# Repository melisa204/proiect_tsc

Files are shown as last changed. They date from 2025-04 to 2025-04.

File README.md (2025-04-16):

# TSC-Project

## BOM (Bill Of Materials)

| Component  | Supplier Link | Datasheet |
|---|---|---|
| 112A-TAAR-R03 | [Model](https://store.comet.srl.ro/Catalogue/Product/43497/) | [Datasheet](https://www.snapeda.com/parts/112A-TAAR-R03/Attend/datasheet/) |
| 744043680 | [Model](https://ro.mouser.com/ProductDetail/Wurth-Elektronik/744043680?qs=PGXP4M47uW6VkZq%252BkzjrHA%3D%3D) | [Datasheet](https://www.we-online.com/components/products/datasheet/744043680.pdf) |
| BD5229G-TR | [Model](https://componentsearchengine.com/part-view/BD5229G-TR/ROHM%20Semiconductor) | [Datasheet](https://fscdn.rohm.com/en/products/databook/datasheet/ic/power/voltage_detector/bd52xxg-e.pdf) |
| Capacitor 0402 | [Model](https://ro.mouser.com/c/passive-components/capacitors/ceramic-capacitors/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) | [Datasheet](https://componentsearchengine.com/Datasheets/2/CC0402MRX5R5BB106.pdf) |
| CPH3225A | [Model](https://www.snapeda.com/parts/CPH3225A/Seiko+Instruments/view-part/?ref=snap) | [Datasheet](https://www.snapeda.com/parts/CPH3225A/Seiko%20Instruments/datasheet/) |
| Custom Button | [Model](https://industry.panasonic.com/global/en/products/control/switch/light-touch/number/evqpuj02k) | [Datasheet](https://industry.panasonic.com/global/en/downloads?tab=catalog&small_g_cd=203&part_no=EVQPUJ02K) |
| DS3231SN | [Model](https://www.snapeda.com/parts/DS3231SN%23/Analog+Devices/view-part/?ref=eda) | [Datasheet](https://www.snapeda.com/parts/DS3231SN%23/Analog%20Devices/datasheet/) |
| ESP32 WROVER 0805 Capacitor | [Model](https://componentsearchengine.com/part-view/SD0805S020S1R0/Kyocera%20AVX) | [Datasheet]() |
| ESP32 WROVER BME680 Sensor | [Model](https://www.snapeda.com/parts/BME680/Bosch/view-part/?welcome=home) | [Datasheet](https://www.bosch-sensortec.com/media/boschsensortec/downloads/datasheets/bst-bme680-ds001.pdf) |
| ESP32 WROVER MCP73831 Power Management | [Model](https://www.snapeda.com/parts/BME680/Bosch/view-part/?welcome=home) | [Datasheet](https://www.snapeda.com/parts/MCP73831T-2ACI/OT/Microchip/datasheet/) |
| ESP32C6 Varistor 1812 | [Model](https://ro.mouser.com/ProductDetail/EPCOS-TDK/B72520T0350K062?qs=dEfas%2FXlABIszF52uu7vrg%3D%3D) | [Datasheet](https://ro.mouser.com/ProductDetail/EPCOS-TDK/B72520T0350K062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) |
| ESP32C6 WROOM-1-N8| [Model](https://www.snapeda.com/parts/ESP32-C6-WROOM-1-N8/Espressif+Systems/view-part/?ref=eda) | [Datasheet](https://www.snapeda.com/parts/ESP32-C6-WROOM-1-N8/Espressif%20Systems/datasheet/) |
| FH34SRJ-24S-0.5SH | [Model](https://ro.mouser.com/ProductDetail/Hirose-Connector/FH34SRJ-24S-0.5SH99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) | [Datasheet](https://www.snapeda.com/parts/FH34SRJ-24S-0.5SH(99)/Hirose%20Connector/datasheet/) |
| LED Chip 0603 | [Model](https://www.snapeda.com/parts/KP-1608SURCK/Kingbright/view-part/?ref=search&t=LED%200603) | [Datasheet](https://www.snapeda.com/parts/KP-1608SURCK/Kingbright/datasheet/) |
| MAX17048G+T10 | [Model](https://www.snapeda.com/parts/MAX17048G+T10/Analog+Devices/view-part/?ref=eda) | [Datasheet](https://www.snapeda.com/parts/MAX17048G+T10/Analog%20Devices/datasheet/) |
| MBR0530 Schottky Diode | [Model](https://www.snapeda.com/parts/MBR0530/Onsemi/view-part/?ref=snap) | [Datasheet](https://www.snapeda.com/parts/MBR0530/ON%20Semiconductor/datasheet/) |
| PGB1010603MR | [Model](https://www.snapeda.com/parts/PGB1010603MR/Littelfuse/view-part/?ref=eda) | [Datasheet](https://www.snapeda.com/parts/PGB1010603MR/Littelfuse%20Inc./datasheet/) |
| QWIIC Connector | [Model](https://www.snapeda.com/parts/PRT-14417/SparkFun/view-part/) | [Datasheet](https://www.snapeda.com/parts/PRT-14417/SparkFun%20Electronics/datasheet/) |
| RCL CPOL 3528 | [Model](https://www.snapeda.com/parts/CPH3225A/Seiko+Instruments/view-part/?ref=eda) | [Datasheet](https://s3.amazonaws.com/snapeda/datasheet/TAJB475K025RNJ_AVX.pdf) |
| Resistor 0402 | [Model](https://grabcad.com/library/resistor-0402-1) | [Datasheet](https://www.yageo.com/upload/media/product/products/datasheet/rchip/PYu-RC_Group_51_RoHS_L_12.pdf) |
| SI1308EDL-T1-GE3 MOSFET | [Model](https://www.snapeda.com/parts/SI1308EDL-T1-GE3/Vishay+Siliconix/view-part/?welcome=home&ref=eda) | [Datasheet](https://www.snapeda.com/parts/SI1308EDL-T1-GE3/Vishay%20Siliconix/datasheet/) |
| SJ | [Model](https://grabcad.com/library/solder-jumpers-1) | [Datasheet]() |
| USB4110-GF-A | [Model](https://componentsearchengine.com/part-view/USB4110-GF-A/GCT%20(GLOBAL%20CONNECTOR%20TECHNOLOGY)) | [Datasheet](https://gct.co/files/drawings/usb4110.pdf) |
| USBLC6-2SC6Y | [Model](https://www.snapeda.com/parts/USBLC6-2SC6Y/STMicroelectronics/view-part/?welcome=home&ref=eda) | [Datasheet](https://www.snapeda.com/parts/USBLC6-2SC6Y/STMicroelectronics/datasheet/) |
| W25Q512JVEIQ | [Model](https://www.snapeda.com/parts/W25Q512JVEIQ/Winbond+Electronics/view-part/?ref=eda) | [Datasheet](https://www.winbond.com/resource-files/W25Q512JV%20SPI%20RevB%2006252019%20KMS.pdf) |
| XC6220A331MR-G | [Model](https://componentsearchengine.com/part-view/XC6220A331MR-G/Torex) | [Datasheet](https://product.torexsemi.com/system/files/series/xc6220.pdf) |

## Power Consumption Estimation
Block Diagram

## Hardware Description  

1. Microcontroller – ESP32-C6-WROOM-1-N8
The ESP32-C6 serves as the main processing unit, managing overall system operations, interfacing with
sensors and external modules, and overseeing power management tasks.
Architecture: 32-bit RISC-V
Clock Speed: 160 MHz
Wireless Connectivity: Wi-Fi 6 (2.4 GHz), Bluetooth 5.0

3. Power Management & Battery Battery Type: Li-Po (Lithium Polymer)
Capacity: 3.7V, 1800mAh
Charging Circuit: MCP73831T
Input Voltage: 5V via USB-C
Protection Features: Overcharge and deep discharge protection
Voltage Regulator: LDO regulator ensures a stable 3.3V power supply to all components.

4. Display - E-Paper (E-Ink) Screen
Size: 7.5 inches
Resolution: 800x480 pixels
Communication Interface: SPI

5. SD Card Module
Type: MicroSD (Supports FAT32)
Interface: SPI

6. External NOR Flash
Capacity: 64MB
Interface: SPI

7. Environmental Sensor - BME688
Functions: Measures temperature, humidity, air pressure, and gas levels.
Communication Interface: I2C 

8. Real-Time Clock (RTC) - DS3231SN
Functionality: Maintains time and date even when the system is powered off.
Communication Interface: I2C 

9. USB-C Connector & ESD Protection
Functionality: Provides power input and data transfer capability.
Protection: Integrated ESD protection and Schottky diode for reverse polarity safety. 

10. Buttons & User Input
Tactile Push Buttons

11. Communication Interfaces
GPIO: Used for button controls and general I/O operations.
SPI: Used for SD card, external flash memory, and e-paper display.
I2C: Used for the BME688 environmental sensor and DS3231SN RTC module.
UART: Used for debugging and serial communication.
Wi-Fi & Bluetooth: Provided by ESP32-C6, allowing wireless connectivity.

## Power Consumption Estimation

| Component | Current Draw (mA) | Voltage (V) | Power (mW) |
|---|---|---|---|
| ESP32-C6 (Wi-Fi active)  |200 |3.3 |660
| E-Paper Display (Updating) | 40 | 3.3 | 132 |
| BME688 Sensor (Measuring)| 3.1 | 3.3 | 10.23 |
| RTC Module (Active) | 0.15 | 3.3 | 0.495 |
| SD Card (Active) | 50 | 3.3 | 165 |
| Externar NOR Flash | 25 | 3.3 | 82.5 |
| Total Estimated Power Consumption | ~318.5mA | 3.3 | 1050.72 |

## ESP32-C6 Pin Mapping  

| Component | ESP32-C6 Pin(s) | Interface | Purpose |
|---|---|---|---|
| **E-Paper Display** | IO7 (MOSI), IO6 (SCK), IO10 (CS), IO5 (DC), IO23 (RST), IO3 (BUSY) | SPI | Transfers image data to the display and controls its state. |
| **MicroSD Card** | IO7 (MOSI), IO6 (SCK), IO4 (SS_SD), IO2 (MISO) | SPI | Allows storage and retrieval of e-book files. |
| **Environmental Sensor (BME688)** | IO21 (SDA), IO22 (SCL) | I2C | Reads temperature, humidity, pressure, and air quality data. |
| **RTC Module (DS3231)**  | IO21 (SDA), IO22 (SCL), IO18 (RST), IO1 (32KHz), IO0 (INT_RTC) | I2C | Keeps track of time even when ESP32 is off. |
| **External NOR Flash** | IO11 (CS), IO6 (SCK), IO2 (MISO), IO7 (MOSI) | SPI | Provides additional storage for application data. |
| **Battery Monitoring** | IO21 (SDA), IO22 (SCL) | I2C | Reads battery voltage and charge status. |
| **USB-C Connection** | GPIOs through voltage regulation | USB | Powers and programs the ESP32-C6. |
| **Control Buttons** | IO9 (BOOT), IO15 (CHANGE), EN (RESET) | GPIO | User input for device interactions. |
|

## Additional Design Notes
### Footprint Adjustments
Diode (SMD-Hole): The original footprint had pad holes that were too small, which would have caused soldering issues.
The pad size was updated to 35mil x 190mil to ensure manufacturability and a reliable electrical connection.

U4 – MAX17048G+T10: The VBAT power trace was designed with a width of 0.3mm, based on implementation constraints
However, the footprint had pin widths of only 0.27mm, resulting in asymmetry and inconsistent routing. The pin sizes
were adjusted to match the trace width and maintain design symmetry.

### Routing & Ground Plane
Power traces were routed only on the top layer, which required the use of approximately 110 vias to allow for
signal routing on the bottom layer.

The ground plane (GND) was added after routing was completed, applied to both top and bottom layers to ensure
low-impedance grounding and reduced EMI.

### Component Placement
Test pads (TPs) were placed near the edges of the board and close to major components for easy debugging access.

### Schematic & 3D Model Issues
After completing the routing process, updates to the 3D models led to pin order reversals in certain 2-pin components, 
which disrupted existing connections. The issue was resolved by rotating the affected components 180° and re-aligning their 
pins accordingly.

### Enclosure & 3D Integration
3D components were imported using two methods, depending on how frequently each part appeared in the schematic.

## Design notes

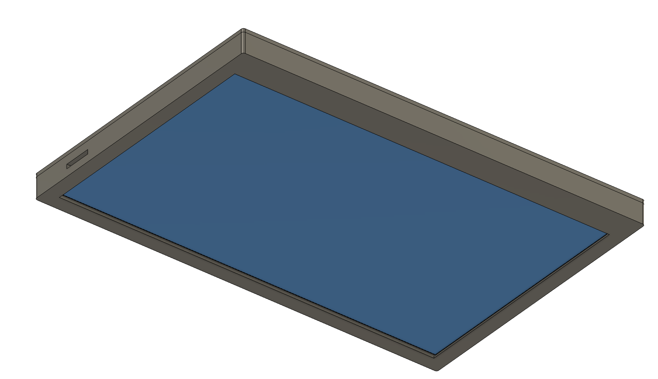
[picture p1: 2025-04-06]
Images/Screenshot 2025-04-06 at 20.57.26.png

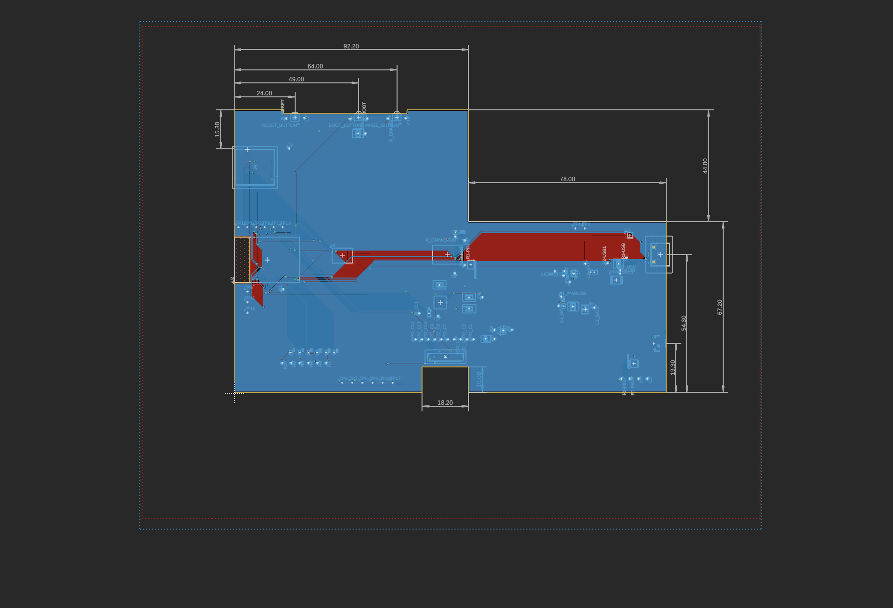
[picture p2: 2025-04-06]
Images/Screenshot 2025-04-06 at 20.54.19.png

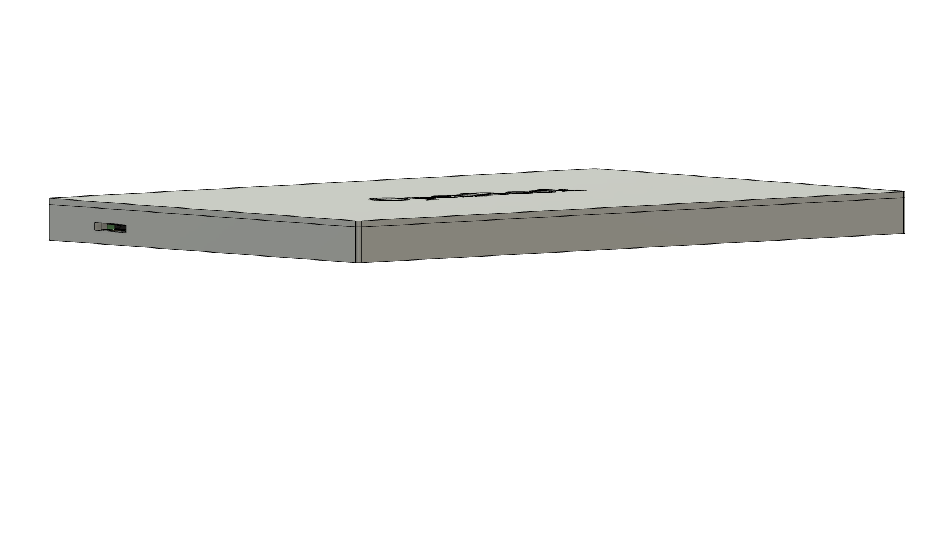
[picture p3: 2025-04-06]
Images/Screenshot 2025-04-06 at 20.57.17.png

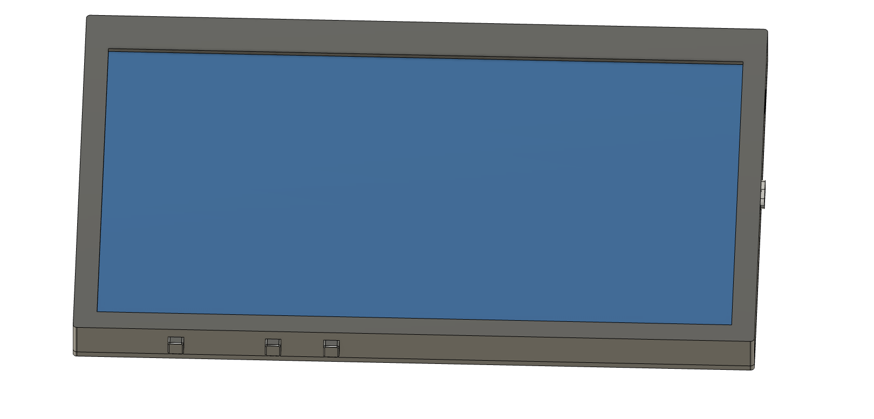
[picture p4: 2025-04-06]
Images/Screenshot 2025-04-06 at 20.56.48.png

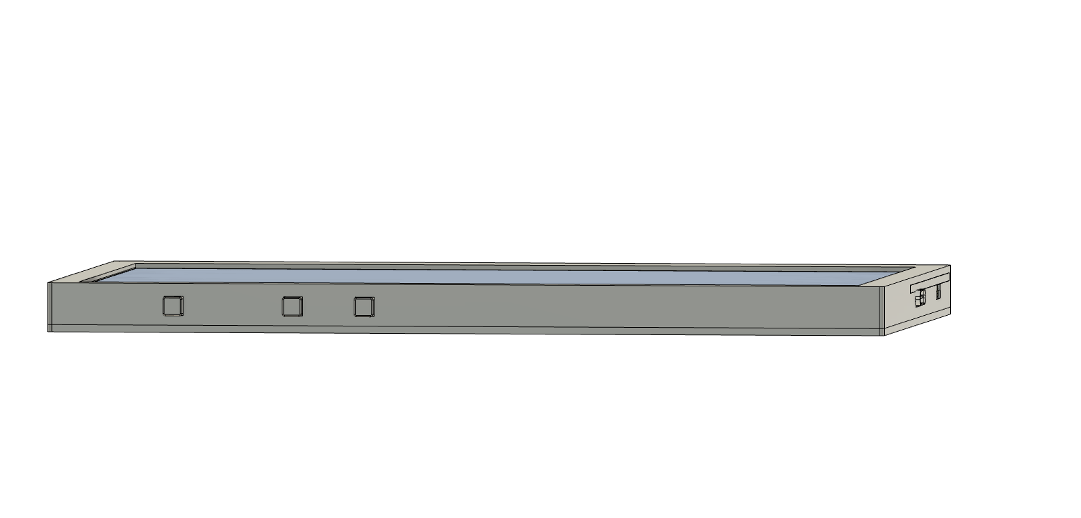
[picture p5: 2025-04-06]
Images/Screenshot 2025-04-06 at 20.56.39.png

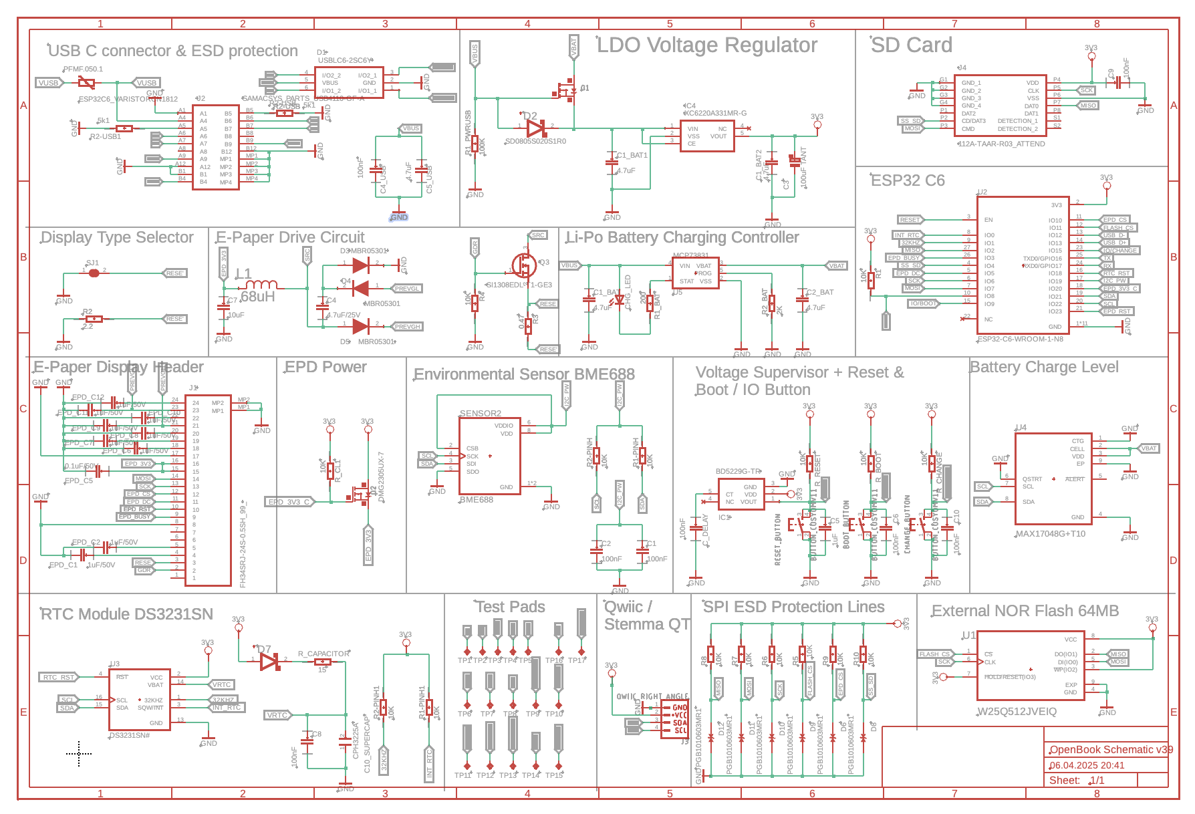
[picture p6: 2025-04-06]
Images/Screenshot 2025-04-06 at 20.53.59.png

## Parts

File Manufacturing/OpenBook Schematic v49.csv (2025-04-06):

Qty | Value | Device | Package | Parts | Description | ARROW_PART_NUMBER | ARROW_PRICE-STOCK | AVAILABILITY | CHECK_PRICES | COPYRIGHT | DESCRIPTION | HEIGHT | MANUFACTURER_NAME | MANUFACTURER_PART_NUMBER | MF | MFR_NAME | MINE | MOUSER_PART_NUMBER | MOUSER_PRICE-STOCK | MOUSER_TESTING_PART_NUMBER | MOUSER_TESTING_PRICE-STOCK | MP | PACKAGE | POPULARITY | PRICE | PROD_ID | PURCHASE-URL | R2-USB | SNAPEDA_LINK | SPICEPREFIX | TP_SIGNAL_NAME | VALUE
1 |  | ADAFRUIT_LEDCHIP-LED0603 | ADAFRUIT_CHIP-LED0603 | CHG_LED | LED
1 |  | SJ | SJ | SJ1 | SMD solder JUMPER |  |  |  |  |  |  |  |  |  |  |  |  |  |  |  |  |  |  | 3
1 | 0.1uF/50V | EAGLE-LTSPICE_C | EAGLE-LTSPICE_C0402 | EPD_C5 | CAPACITOR, European symbol
1 | 0.47 | ESP32_WROVER_EAGLE-LTSPICE_R | ESP32_WROVER_EAGLE-LTSPICE_R0402 | R3 | RESISTOR, European symbol
1 | 100K | ESP32_WROVER_EAGLE-LTSPICE_R | ESP32_WROVER_EAGLE-LTSPICE_R0402 | R1_PWRUSB | RESISTOR, European symbol
8 | 100nF | EAGLE-LTSPICE_C | EAGLE-LTSPICE_C0402 | C1, C2, C4_USB, C6, C8, C9, C10, C_DELAY | CAPACITOR, European symbol
1 | 100uF TANT | RCL_CPOL-EUCT3528 | RCL_CT3528 | C3 | POLARIZED CAPACITOR, European symbol |  |  |  |  |  |  |  |  |  |  |  |  |  |  |  |  |  |  | 0 |  |  |  |  |  | C
16 | 10K | ESP32_WROVER_EAGLE-LTSPICE_R | ESP32_WROVER_EAGLE-LTSPICE_R0402 | R1, R1-PINH, R1-PINH1, R2-PINH, R2-PINH1, R4, R5, R6, R7, R8, R9, R10, R_BOOT, R_CHANGE, R_CL1, R_RESET | RESISTOR, European symbol
1 | 10uF | EAGLE-LTSPICE_C | EAGLE-LTSPICE_C0402 | C7 | CAPACITOR, European symbol
1 | 112A-TAAR-R03_ATTEND | 112A-TAAR-R03_ATTEND | 112ATAARR03ATTEND | J4 | Micro SD Card Socket, Push-Push Type, Top Mount, SMT, H=1.83mm, 10u |  |  |  |  |  | Micro SD Card Socket | Push-Push Type | Top Mount | SMT | H=1.83mm | 10u | 1.9mm | ATTEND | 112A-TAAR-R03 ATTEND
1 | 15 | ESP32_WROVER_EAGLE-LTSPICE_R | ESP32_WROVER_EAGLE-LTSPICE_R0402 | R_CAPACITOR | RESISTOR, European symbol
1 | 1uF | EAGLE-LTSPICE_C | EAGLE-LTSPICE_C0402 | C5 | CAPACITOR, European symbol
9 | 1uF/50V | EAGLE-LTSPICE_C | EAGLE-LTSPICE_C0402 | EPD_C1, EPD_C2, EPD_C6, EPD_C7, EPD_C8, EPD_C9, EPD_C10, EPD_C11, EPD_C12 | CAPACITOR, European symbol
1 | 2.2 | ESP32_WROVER_EAGLE-LTSPICE_R | ESP32_WROVER_EAGLE-LTSPICE_R0402 | R2 | RESISTOR, European symbol
1 | 200 | ESP32_WROVER_EAGLE-LTSPICE_R | ESP32_WROVER_EAGLE-LTSPICE_R0402 | R1_BAT | RESISTOR, European symbol
1 | 20V/4.2A/52mΩ/1.4W | ESP32_WROVER_SPARKFUN-DISCRETESEMI_MOSFET_PCH | ESP32_WROVER_SPARKFUN-DISCRETESEMI_SOT23-3 | Q1 | P-channel MOSFETs
1 | 20V/4.2A/52mΩ/1.4W | ESP32_WROVER_SPARKFUN-DISCRETESEMI_MOSFET_PCH | ESP32_WROVER_SPARKFUN-DISCRETESEMI_SOT23-3 | Q2 | P-channel MOSFETs |  |  |  |  |  |  |  |  |  |  |  | DMG2305UX-7
1 | 2K | ESP32_WROVER_EAGLE-LTSPICE_R | ESP32_WROVER_EAGLE-LTSPICE_R0402 | R2_BAT | RESISTOR, European symbol
5 | 4.7uF | EAGLE-LTSPICE_C | EAGLE-LTSPICE_C0402 | C1_BAT, C1_BAT1, C1_BAT2, C2_BAT, C5_USB | CAPACITOR, European symbol
1 | 4.7uF/25V | EAGLE-LTSPICE_C | EAGLE-LTSPICE_C0402 | C4 | CAPACITOR, European symbol
1 | 5k1 | ESP32_WROVER_EAGLE-LTSPICE_R | ESP32_WROVER_EAGLE-LTSPICE_R0402 | R2-USB1 | RESISTOR, European symbol
1 | 5k1 | ESP32_WROVER_EAGLE-LTSPICE_R | ESP32_WROVER_EAGLE-LTSPICE_R0402 | R2-USB | RESISTOR, European symbol |  |  |  |  |  |  |  |  |  |  |  |  |  |  |  |  |  |  |  |  |  |  | 5k1
1 | 68uH | 744043680IND_4828-WE-TPC_WRE | IND_4828-WE-TPC_WRE | L1 |  |  |  |  |  | Copyright (C) 2024 Ultra Librarian. All rights reserved. |  |  |  | 744043680 |  | Wurth Electronics
1 | BD5229G-TR | BD5229G-TR | SOT95P280X125-5N | IC1 | Voltage Detector with Adjustable Delay Time: CMOS processes are utilized to develop high precision, low current consumption CMOS reset ICs that allow arbitrary setting of the delay time. The extensive lineup includes both Nch Open Drain and CMOS output types in a wide range of detection voltages (from 2.3V to 6.0V, in 0.1V steps), enabling selection of the ideal solution based on customer requirements. In addition, the entire series is of course both lead-free and RoHS-compliant. |  |  |  |  |  | Voltage Detector with Adjustable Delay Time: CMOS processes are utilized to develop high precision | low current consumption CMOS reset ICs that allow arbitrary setting of the delay time. The extensive lineup includes both Nch Open Drain and CMOS output types in a wide range of detection voltages (from 2.3V to 6.0V | in 0.1V steps) | enabling selection of the ideal solution based on customer requirements. In addition | the entire series is of course both lead-free and RoHS-compliant. | 1.25mm | ROHM Semiconductor | BD5229G-TR |  |  |  | 755-BD5229G-TR | https://www.mouser.co.uk/ProductDetail/ROHM-Semiconductor/BD5229G-TR?qs=4kLU8WoGk0vvnhrrYwdszw%3D%3D
1 | BME688 | ESP32_WROVER_BME680_BME680 | ESP32_WROVER_BME680_PSON80P300X300X100-8N | SENSOR2 | Integrated Environmental Unit |  |  | Unavailable |  |  | Integrated Environmental Unit |  |  |  | Bosch Sensortec |  |  |  |  |  |  | BME680 | LGA-8 Bosch Tools |  | None
3 | BUTTON_CUSYOMV11 | BUTTON_CUSYOMV11 | MYBUTTON | BOOT_BUTTON, CHANGE_BUTTON, RESET_BUTTON
1 | CPH3225A | CPH3225A | CAPCP3225X100N | C10_SUPERCAP | Cap 0.011F 3.3V 1210 Flat Check availability |  |  | Not in stock | https://www.snapeda.com/parts/CPH3225A/Seiko+Instruments/view-part/?ref=eda |  | 11 mF (EDLC) Supercapacitor 3.3 V 1210 (3225 Metric) - - |  |  |  | Seiko Instruments |  |  |  |  |  |  | CPH3225A | 1210 Seiko |  | None |  | https://www.snapeda.com/api/url_track_click_mouser/?unipart_id=562593&manufacturer=Seiko Instruments&part_name=CPH3225A&search_term=None |  | https://www.snapeda.com/parts/CPH3225A/Seiko+Instruments/view-part/?ref=snap
1 | DS3231SN# | DS3231SN# | SOIC127P1032X265-16N | U3 | Real Time Clock Serial 16-Pin SOIC W T/R Check availability |  |  | In Stock | https://www.snapeda.com/parts/DS3231SN%23/Analog+Devices/view-part/?ref=eda |  | Extremely Accurate I²C-Integrated RTC/TCXO/Crystal |  |  |  | Analog Devices |  |  |  |  |  |  | DS3231SN# | SOIC-16 Maxim |  | None |  | https://www.snapeda.com/api/url_track_click_mouser/?unipart_id=99048&manufacturer=Analog Devices&part_name=DS3231SN#&search_term=None |  | https://www.snapeda.com/parts/DS3231SN%23/Analog+Devices/view-part/?ref=snap
1 | ESP32-C6-WROOM-1-N8 | ESP32-C6-WROOM-1-N8 | XCVR_ESP32-C6-WROOM-1-N8 | U2 | Check availability |  |  | In Stock | https://www.snapeda.com/parts/ESP32-C6-WROOM-1-N8/Espressif+Systems/view-part/?ref=eda |  | Multiprotocol Modules ESP32-C6 module | Wi-Fi 6 in 2.4 GHz band | Bluetooth 5 | Zigbee 3.0 and Thread. ESP34-WROOM Compatible - ENGINEERING SAMPLE |  |  |  | Espressif Systems |  |  |  |  |  |  | ESP32-C6-WROOM-1-N8 | None |  | None |  |  |  | https://www.snapeda.com/parts/ESP32-C6-WROOM-1-N8/Espressif+Systems/view-part/?ref=snap
1 | ESP32C6_VARISTORCN1812 | ESP32C6_VARISTORCN1812 | ESP32C6_VARISTOR_CT/CN1812 | PFMF.050.1 | VARISTOR |  |  |  |  |  |  |  |  |  |  |  |  |  |  |  |  |  |  | 0
1 | FH34SRJ-24S-0.5SH_99_ | FH34SRJ-24S-0.5SH_99_ | FH34SRJ24S05SH99 | J1 | (0.50mm) Surface Mount, Right Angle |  |  |  |  |  | 24 Position FFC | FPC Connector Contacts | (0.50mm) Surface Mount | Right Angle | 1.1mm | Hirose | FH34SRJ-24S-0.5SH(99) |  |  |  | 798-FH34SRJ24S05SH99 | https://www.mouser.co.uk/ProductDetail/Hirose-Connector/FH34SRJ-24S-0.5SH99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
1 | MAX17048G+T10 | MAX17048G+T10 | SON50P200X200X80-9N | U4 | Check availability |  |  | In Stock | https://www.snapeda.com/parts/MAX17048G+T10/Analog+Devices/view-part/?ref=eda |  | 3µA 1-Cell/2-Cell Fuel Gauge with ModelGauge |  |  |  | Analog Devices |  |  |  |  |  |  | MAX17048G+T10 | TDFN-8 Maxim |  | None |  | https://www.snapeda.com/api/url_track_click_mouser/?unipart_id=329239&manufacturer=Analog Devices&part_name=MAX17048G+T10&search_term=None |  | https://www.snapeda.com/parts/MAX17048G+T10/Analog+Devices/view-part/?ref=snap
3 | MBR05301 | MBR05301 | SOD3716X135N | D3, D4, D5 | ON SEMICONDUCTOR - MBR0530 - DIODE, SCHOTTKY, 0.5A, 30V, SOD-123
1 | MCP73831 | ESP32_WROVER_SPARKFUN-IC-POWER_MCP73831 | ESP32_WROVER_SPARKFUN-IC-POWER_SOT23-5 | U5 | MCP73831T Li-Ion, Li-Pol Controller |  |  |  |  |  |  |  |  |  |  |  |  |  |  |  |  |  |  |  |  | IC-09995
6 | PGB1010603MR1 | PGB1010603MR1 | DIOC1608X36N | D6, D8, D9, D10, D11, D12 | Check availability
1 | QWIIC_RIGHT_ANGLE | QWIIC_CONNECTORJS-1MM | JST04_1MM_RA | J3 | SparkFun I2C Standard Qwiic Connector |  |  |  |  |  |  |  |  |  |  |  |  |  |  |  |  |  |  |  |  | CONN-13694 |  |  |  |  |  | QWIIC_RIGHT_ANGLE
1 | SAMACSYS_PARTS_USB4110-GF-A | SAMACSYS_PARTS_USB4110-GF-A | SAMACSYS_PARTS_USB4110GFA | J2 | CONN USB 2.0 TYPE-C R/A SMT |  |  |  |  |  | CONN USB 2.0 TYPE-C R/A SMT | 3.26mm | GCT (GLOBAL CONNECTOR TECHNOLOGY) | USB4110-GF-A |  |  |  | 640-USB4110-GF-A | https://www.mouser.co.uk/ProductDetail/GCT/USB4110-GF-A?qs=KUoIvG%2F9IlYiZvIXQjyJeA%3D%3D
1 | SD0805S020S1R0 | ESP32_WROVER_AVX---SD0805S020S1R0_AVX_SD0805S020S1R0_0_0 | ESP32_WROVER_AVX---SD0805S020S1R0_AVX_SD0805S020S1R0_0 | D7 | Schottky Barrier Rectifier Diode
1 | SD0805S020S1R0 | ESP32_WROVER_AVX---SD0805S020S1R0_AVX_SD0805S020S1R0_0_0 | ESP32_WROVER_AVX---SD0805S020S1R0_AVX_SD0805S020S1R0_0 | D2 | Schottky Barrier Rectifier Diode |  |  |  |  |  |  |  |  |  |  |  | SD0805S020S1R0
1 | SI1308EDL-T1-GE3 | SI1308EDL-T1-GE3 | SOT65P210X110-3N | Q3 | MOSFET N-Ch 30V 1.5A TrenchFET SC70 Vishay Si1308EDL-T1-GE3 N-channel MOSFET Transistor, 1.5 A, 30 V, 3-Pin SC-70 |  |  | In Stock | https://www.snapeda.com/parts/SI1308EDL-T1-GE3/Vishay+Siliconix/view-part/?ref=eda |  | Si1308EDL-T1-GE3 N-channel MOSFET Transistor | 1.5 A | 30 V | 3-Pin SC-70 | Siliconix / Vishay SI1308EDL-T1-GE3 |  |  |  | Vishay Siliconix |  |  |  |  |  |  | SI1308EDL-T1-GE3 | SOT-323 Vishay Semiconductor |  | None |  | https://www.snapeda.com/api/url_track_click_mouser/?unipart_id=274603&manufacturer=Vishay Siliconix&part_name=SI1308EDL-T1-GE3&search_term=None |  | https://www.snapeda.com/parts/SI1308EDL-T1-GE3/Vishay+Siliconix/view-part/?ref=snap
17 | TPTP20R | TPTP20R | TP20R | TP1, TP2, TP3, TP4, TP5, TP6, TP7, TP8, TP9, TP10, TP11, TP12, TP13, TP14, TP15, TP16, TP17 | Test pad |  |  |  |  |  |  |  |  |  |  |  |  |  |  |  |  |  |  | 2
1 | USBLC6-2SC6Y | USBLC6-2SC6Y | SOT95P280X145-6N | D1 | Low Cap. ESD Protection Auto SOT-23-6 STMicroelectronics USBLC6-2SC6Y, Dual Uni-Directional TVS Diode Array, 6-Pin SOT-23 |  |  | In Stock | https://www.snapeda.com/parts/USBLC6-2SC6Y/STMicroelectronics/view-part/?ref=eda |  | 17V Clamp 5A (8/20µs) Ipp Tvs Diode Surface Mount SOT-23-6 |  |  |  | STMicroelectronics |  |  |  |  |  |  | USBLC6-2SC6Y | SOT-23-6 STMicroelectronics |  | None |  |  |  | https://www.snapeda.com/parts/USBLC6-2SC6Y/STMicroelectronics/view-part/?ref=snap
1 | W25Q512JVEIQ | W25Q512JVEIQ | SON127P600X800X80-9N | U1 | Check availability |  |  | In Stock | https://www.snapeda.com/parts/W25Q512JVEIQ/Winbond+Electronics/view-part/?ref=eda |  | FLASH - NOR Memory IC 512Mb (64M x 8) SPI - Quad I/O 133 MHz 8-WSON (8x6) |  |  |  | Winbond Electronics |  |  |  |  |  |  | W25Q512JVEIQ | Package |  | None |  |  |  | https://www.snapeda.com/parts/W25Q512JVEIQ/Winbond+Electronics/view-part/?ref=snap
1 | XC6220A331MR-G | XC6220A331MR-G | SOT95P280X120-5N | IC4 | LDO Voltage Regulators |  |  |  |  |  | LDO Voltage Regulators | 1.2mm | Torex | XC6220A331MR-G |  |  |  | 865-XC6220A331MR-G | https://www.mouser.co.uk/ProductDetail/Torex-Semiconductor/XC6220A331MR-G?qs=AsjdqWjXhJ8ZSWznL1J0gg%3D%3D

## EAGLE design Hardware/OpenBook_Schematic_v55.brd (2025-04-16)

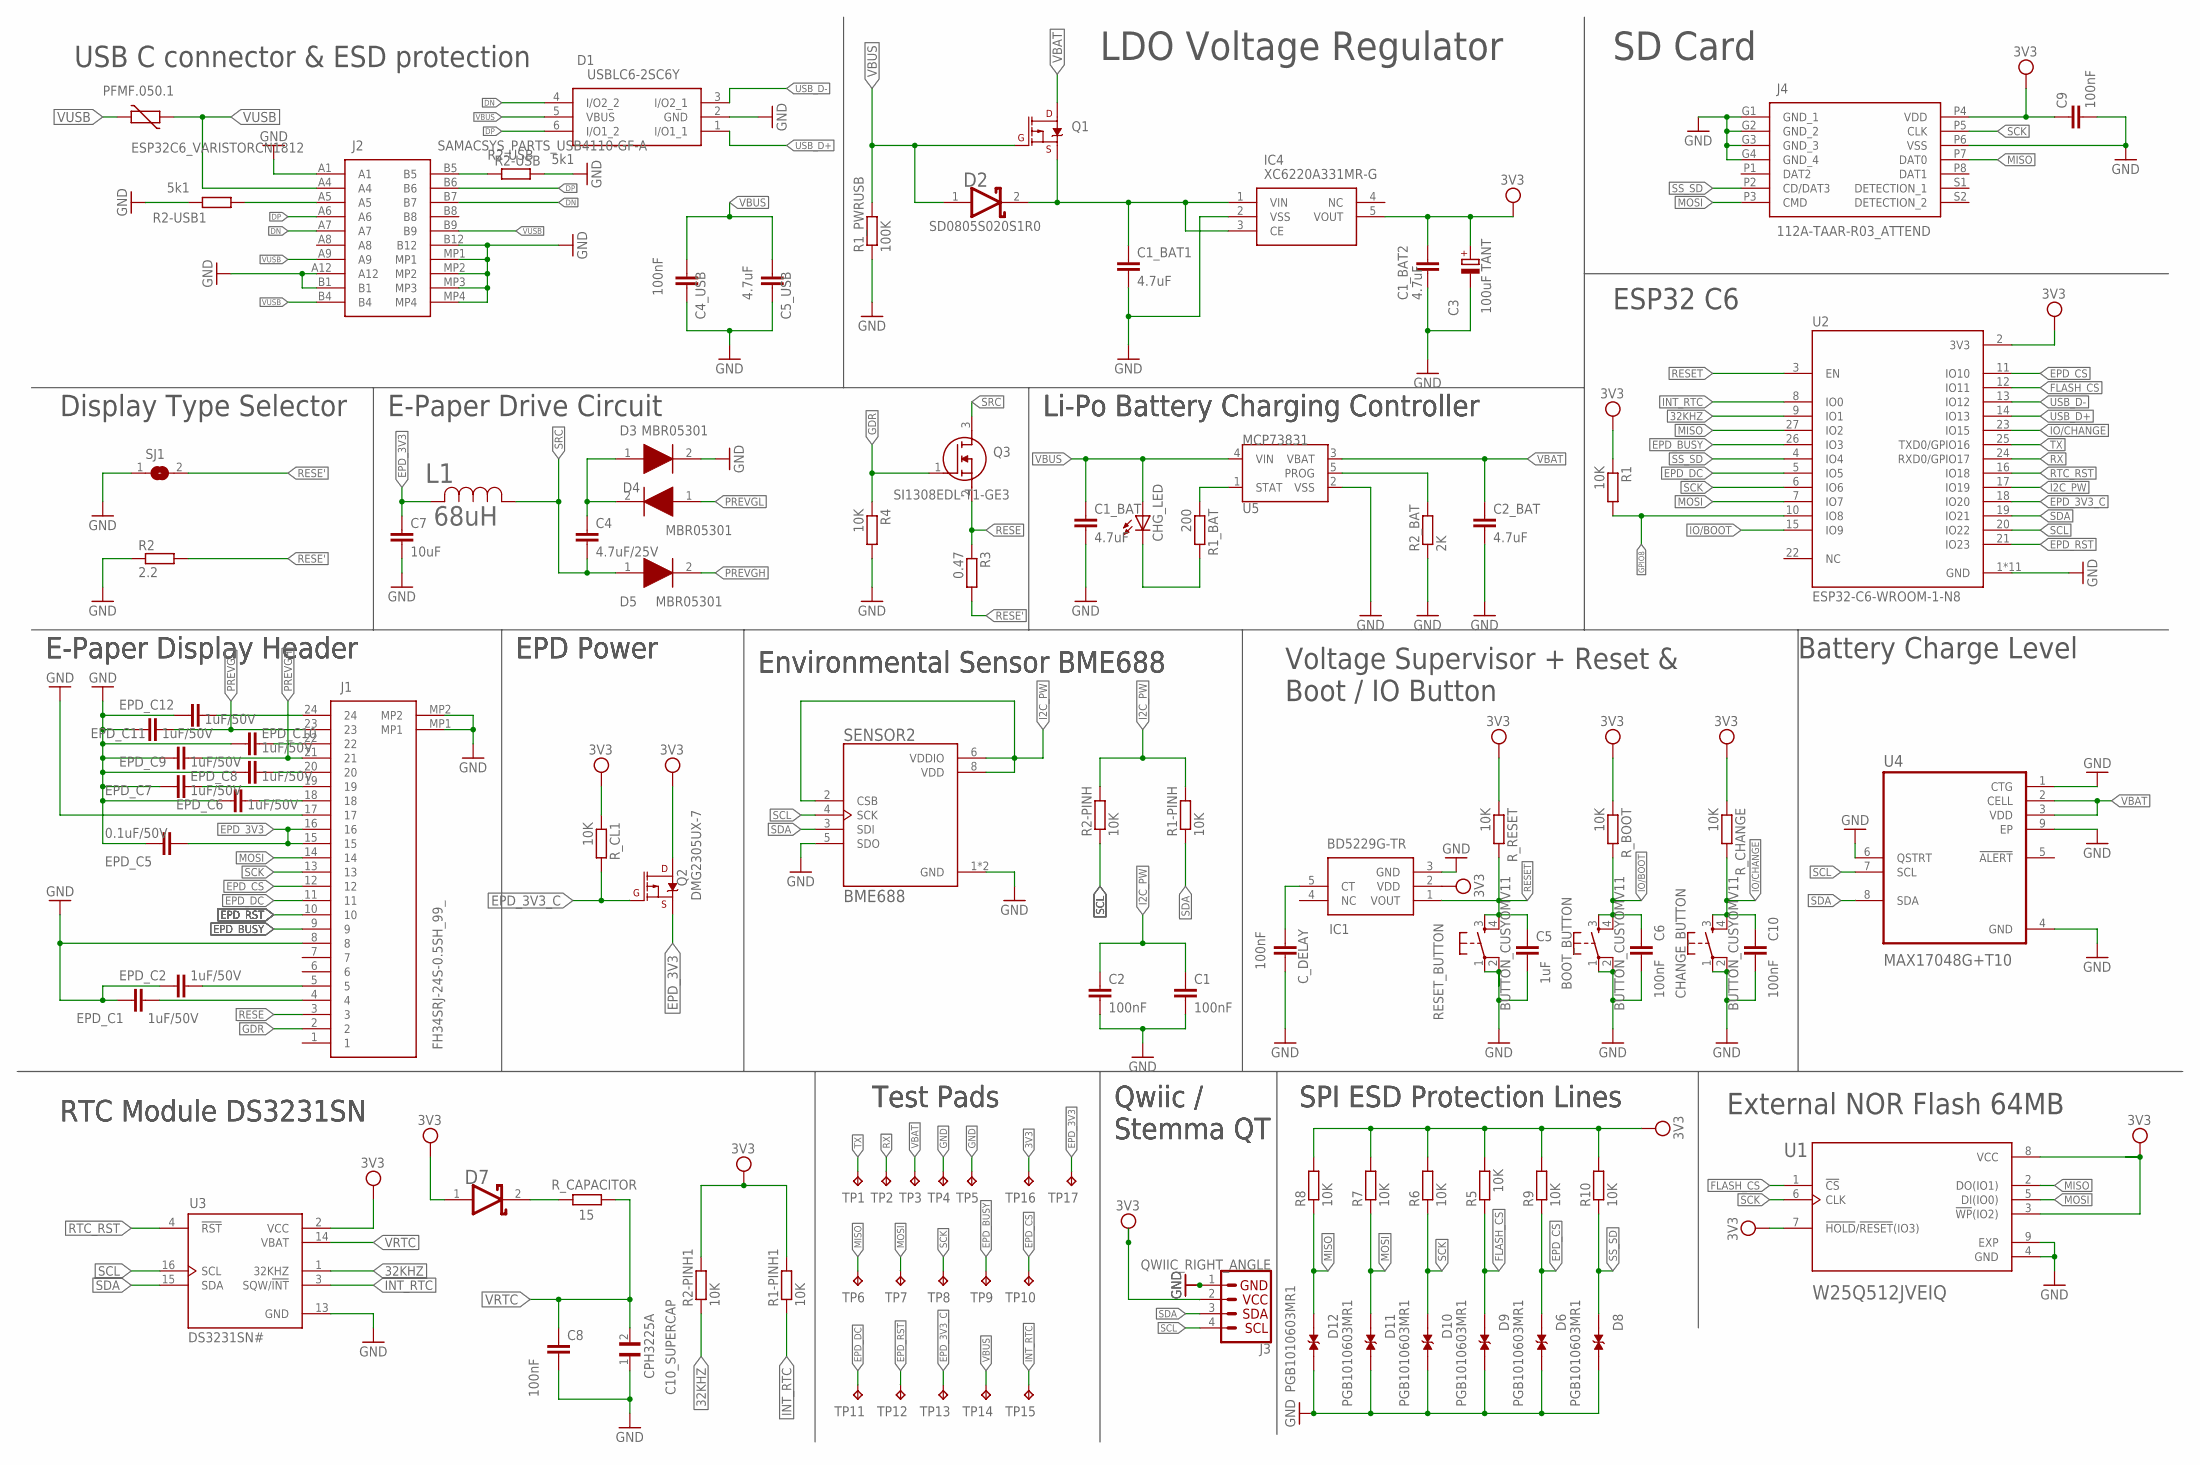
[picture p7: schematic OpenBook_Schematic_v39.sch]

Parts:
BOOT_BUTTON: BUTTON_CUSYOMV11; MYBUTTON
C1, C2, C4_USB, C6, C8, C9, C10: 100nF; EAGLE-LTSPICE_C0402
C1_BAT, C1_BAT1, C1_BAT2, C2_BAT, C5_USB: 4.7uF; EAGLE-LTSPICE_C0402
C3: 100uF TANT; RCL_CT3528
C4: 4.7uF/25V; EAGLE-LTSPICE_C0402
C5: 1uF; EAGLE-LTSPICE_C0402
C7: 10uF; EAGLE-LTSPICE_C0402
C10_SUPERCAP: CPH3225A; CAPCP3225X100N
CHANGE_BUTTON: BUTTON_CUSYOMV11; MYBUTTON
CHG_LED: ADAFRUIT_LEDCHIP-LED0603; ADAFRUIT_CHIP-LED0603
C_DELAY: 100nF; EAGLE-LTSPICE_C0402
D1: USBLC6-2SC6Y; SOT95P280X145-6N
D2, D7: SD0805S020S1R0; ESP32_WROVER_AVX---SD0805S020S1R0_AVX_SD0805S020S1R0_0
D3, D4, D5: MBR05301; SOD3716X135N
D6, D8, D9, D10, D11, D12: PGB1010603MR1; DIOC1608X36N
EPD_C1, EPD_C2, EPD_C6, EPD_C7, EPD_C8, EPD_C9, EPD_C10, EPD_C11, EPD_C12: 1uF/50V; EAGLE-LTSPICE_C0402
EPD_C5: 0.1uF/50V; EAGLE-LTSPICE_C0402
IC1: BD5229G-TR; SOT95P280X125-5N
IC4: XC6220A331MR-G; SOT95P280X120-5N
J1: FH34SRJ-24S-0.5SH_99_; FH34SRJ24S05SH99
J2: SAMACSYS_PARTS_USB4110-GF-A; SAMACSYS_PARTS_USB4110GFA
J3: QWIIC_RIGHT_ANGLE; JST04_1MM_RA
J4: 112A-TAAR-R03_ATTEND; 112ATAARR03ATTEND
L1: 68uH; IND_4828-WE-TPC_WRE
PFMF.050.1: ESP32C6_VARISTORCN1812; ESP32C6_VARISTOR_CT/CN1812
Q1, Q2: 20V/4.2A/52mΩ/1.4W; ESP32_WROVER_SPARKFUN-DISCRETESEMI_SOT23-3
Q3: SI1308EDL-T1-GE3; SOT65P210X110-3N
R1, R1-PINH, R1-PINH1, R2-PINH, R2-PINH1, R4, R5, R6, R7, R8, R9, R10: 10K; ESP32_WROVER_EAGLE-LTSPICE_R0402
R1_BAT: 200; ESP32_WROVER_EAGLE-LTSPICE_R0402
R1_PWRUSB: 100K; ESP32_WROVER_EAGLE-LTSPICE_R0402
R2: 2.2; ESP32_WROVER_EAGLE-LTSPICE_R0402
R2-USB, R2-USB1: 5k1; ESP32_WROVER_EAGLE-LTSPICE_R0402
R2_BAT: 2K; ESP32_WROVER_EAGLE-LTSPICE_R0402
R3: 0.47; ESP32_WROVER_EAGLE-LTSPICE_R0402
RESET_BUTTON: BUTTON_CUSYOMV11; MYBUTTON
R_BOOT: 10K; ESP32_WROVER_EAGLE-LTSPICE_R0402
R_CAPACITOR: 15; ESP32_WROVER_EAGLE-LTSPICE_R0402
R_CHANGE: 10K; ESP32_WROVER_EAGLE-LTSPICE_R0402
R_CL1: 10K; ESP32_WROVER_EAGLE-LTSPICE_R0402
R_RESET: 10K; ESP32_WROVER_EAGLE-LTSPICE_R0402
SENSOR2: BME688; ESP32_WROVER_BME680_PSON80P300X300X100-8N
SJ1: SJ
TP1, TP2, TP3, TP4, TP5, TP6, TP7, TP8, TP9, TP10, TP11, TP12, TP13, TP14, TP15, TP16, TP17: TPTP20R; TP20R
U1: W25Q512JVEIQ; SON127P600X800X80-9N
U2: ESP32-C6-WROOM-1-N8; XCVR_ESP32-C6-WROOM-1-N8
U3: DS3231SN#; SOIC127P1032X265-16N
U4: MAX17048G+T10; SON50P200X200X80-9N
U5: MCP73831; ESP32_WROVER_SPARKFUN-IC-POWER_SOT23-5

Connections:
3V3: C1_BAT2.1, C3.+, C9.1, D7.1 (ANODE), IC1.2 (VDD), IC4.5 (VOUT), J3.2, J4.P4 (VDD), Q2.1 (D), R1.1, R1-PINH1.2, R2-PINH1.2, R5.2, R6.2, R7.2, R8.2, R9.2, R10.2, R_BOOT.1, R_CHANGE.1, R_CL1.1, R_RESET.1, TP16.TP, U1.3 (!WP!(IO2)), U1.7 (!HOLD!/!RESET!(IO3)), U1.8 (VCC), U2.2 (3V3), U3.2 (VCC)
32KHZ: R2-PINH1.1, U2.9 (IO1), U3.1 (32KHZ)
DN: D1.4 (I/O2_2), J2.A7, J2.B7
DP: D1.6 (I/O1_2), J2.A6, J2.B6
EPD_3V3: C7.1, EPD_C5.1, J1.15, J1.16, L1.2, Q2.3 (S), TP17.TP
EPD_3V3_C: Q2.2 (G), R_CL1.2, TP13.TP, U2.18 (IO20)
EPD_BUSY: J1.9, TP9.TP, U2.26 (IO3)
EPD_CS: D6.1, J1.12, R9.1, TP10.TP, U2.11 (IO10)
EPD_DC: J1.11, TP11.TP, U2.5 (IO5)
EPD_RST: J1.10, TP12.TP, U2.21 (IO23)
FLASH_CS: D9.1, R5.1, U1.1 (!CS), U2.12 (IO11)
GDR: J1.2, Q3.1 (G), R4.1
GND: BOOT_BUTTON.1, BOOT_BUTTON.2, C1.2, C1_BAT.2, C1_BAT1.2, C1_BAT2.2, C2.2, C2_BAT.2, C3.-, C4_USB.2, C5.2, C5_USB.2, C6.2, C7.2, C8.2, C9.2, C10.2, C10_SUPERCAP.1, CHANGE_BUTTON.1, CHANGE_BUTTON.2, C_DELAY.2, D1.2 (GND), D3.2 (K), D6.2, D8.2, D9.2, D10.2, D11.2, D12.2, EPD_C1.2, EPD_C2.2, EPD_C5.2, EPD_C6.2, EPD_C7.2, EPD_C8.2, EPD_C9.2, EPD_C10.2, EPD_C11.2, EPD_C12.2, IC1.3 (GND), IC4.2 (VSS), J1.8, J1.17, J1.MP1, J1.MP2, J2.A1, J2.A12, J2.B1, J2.B12, J2.MP1, J2.MP2, J2.MP3, J2.MP4, J3.1, J4.G1 (GND_1), J4.G2 (GND_2), J4.G3 (GND_3), J4.G4 (GND_4), J4.P6 (VSS), R1_PWRUSB.1, R2.1, R2-USB.2, R2-USB1.1, R2_BAT.1, R4.2, RESET_BUTTON.1, RESET_BUTTON.2, SENSOR2.1 (GND), SENSOR2.5 (SDO), SENSOR2.7 (GND), SJ1.1, TP4.TP, TP5.TP, U1.4 (GND), U1.9 (EXP), U2.1 (GND), U2.28 (GND), U2.29_1 (GND), U2.29_2 (GND), U2.29_3 (GND), U2.29_4 (GND), U2.29_5 (GND), U2.29_6 (GND), U2.29_7 (GND), U2.29_8 (GND), U2.29_9 (GND), U3.13 (GND), U4.1 (CTG), U4.4 (GND), U4.6 (QSTRT), U4.9 (EP), U5.2 (VSS)
GPIO8: R1.2, U2.10 (IO8)
I2C_PW: C1.1, C2.1, R1-PINH.2, R2-PINH.2, SENSOR2.2 (CSB), SENSOR2.6 (VDDIO), SENSOR2.8 (VDD), U2.17 (IO19)
INT_RTC: R1-PINH1.1, TP15.TP, U2.8 (IO0), U3.3 (SQW/!INT)
IO/BOOT: BOOT_BUTTON.3, BOOT_BUTTON.4, C6.1, R_BOOT.2, U2.15 (IO9)
IO/CHANGE: C10.1, CHANGE_BUTTON.3, CHANGE_BUTTON.4, R_CHANGE.2, U2.23 (IO15)
MISO: D12.1, J4.P7 (DAT0), R8.1, TP6.TP, U1.2 (DO(IO1)), U2.27 (IO2)
MOSI: D11.1, J1.14, J4.P3 (CMD), R7.1, TP7.TP, U1.5 (DI(IO0)), U2.7 (IO7)
unnamed: C_DELAY.1, IC1.5 (CT)
unnamed: EPD_C6.1, J1.18
unnamed: J2.A5, R2-USB1.2
unnamed: EPD_C1.1, J1.4
unnamed: EPD_C2.1, J1.5
unnamed: EPD_C7.1, J1.19
unnamed: EPD_C8.1, J1.20
unnamed: R1_BAT.1, U5.1 (STAT)
unnamed: EPD_C10.1, J1.22
unnamed: CHG_LED.C, R1_BAT.2
unnamed: J2.B5, R2-USB.1
unnamed: EPD_C12.1, J1.24
unnamed: C4.1, D3.1 (A), D4.2 (K)
unnamed: R2_BAT.2, U5.5 (PROG)
unnamed: C1_BAT1.1, D2.2 (CATHODE), IC4.1 (VIN), IC4.3 (CE), Q1.3 (S)
unnamed: D7.2 (CATHODE), R_CAPACITOR.2
PREVGH: D5.2 (K), EPD_C9.1, J1.21
PREVGL: D4.1 (A), EPD_C11.1, J1.23
RESE: J1.3, Q3.2 (S), R3.1
RESE': R2.2, R3.2, SJ1.2
RESET: C5.1, IC1.1 (VOUT), RESET_BUTTON.3, RESET_BUTTON.4, R_RESET.2, U2.3 (EN)
RTC_RST: U2.16 (IO18), U3.4 (!RST)
RX: TP2.TP, U2.24 (RXD0/GPIO17)
SCK: D10.1, J1.13, J4.P5 (CLK), R6.1, TP8.TP, U1.6 (CLK), U2.6 (IO6)
SCL: J3.4, R2-PINH.1, SENSOR2.4 (SCK), U2.20 (IO22), U3.16 (SCL), U4.7 (SCL)
SDA: J3.3, R1-PINH.1, SENSOR2.3 (SDI), U2.19 (IO21), U3.15 (SDA), U4.8 (SDA)
SRC: C4.2, D5.1 (A), L1.1, Q3.3 (D)
SS_SD: D8.1, J4.P2 (CD/DAT3), R10.1, U2.4 (IO4)
TX: TP1.TP, U2.25 (TXD0/GPIO16)
USB_D+: D1.1 (I/O1_1), U2.14 (IO13)
USB_D-: D1.3 (I/O2_1), U2.13 (IO12)
VBAT: C2_BAT.1, Q1.1 (D), TP3.TP, U4.2 (CELL), U4.3 (VDD), U5.3 (VBAT)
VBUS: C1_BAT.1, C4_USB.1, C5_USB.1, CHG_LED.A, D1.5 (VBUS), D2.1 (ANODE), Q1.2 (G), R1_PWRUSB.2, TP14.TP, U5.4 (VIN)
VRTC: C8.1, C10_SUPERCAP.2, R_CAPACITOR.1, U3.14 (VBAT)
VUSB: J2.A4, J2.A9, J2.B4, J2.B9, PFMF.050.1.1, PFMF.050.1.2

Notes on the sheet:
USB C connector & ESD protection
LDO Voltage Regulator
SD Card
ESP32 C6
RTC Module DS3231SN
Test Pads
Qwiic / Stemma QT
SPI ESD Protection Lines
External NOR Flash 64MB
Battery Charge Level
Voltage Supervisor + Reset & Boot / IO Button
Environmental Sensor BME688
EPD Power
E-Paper Display Header
Li-Po Battery Charging Controller
E-Paper Drive Circuit
Display Type Selector

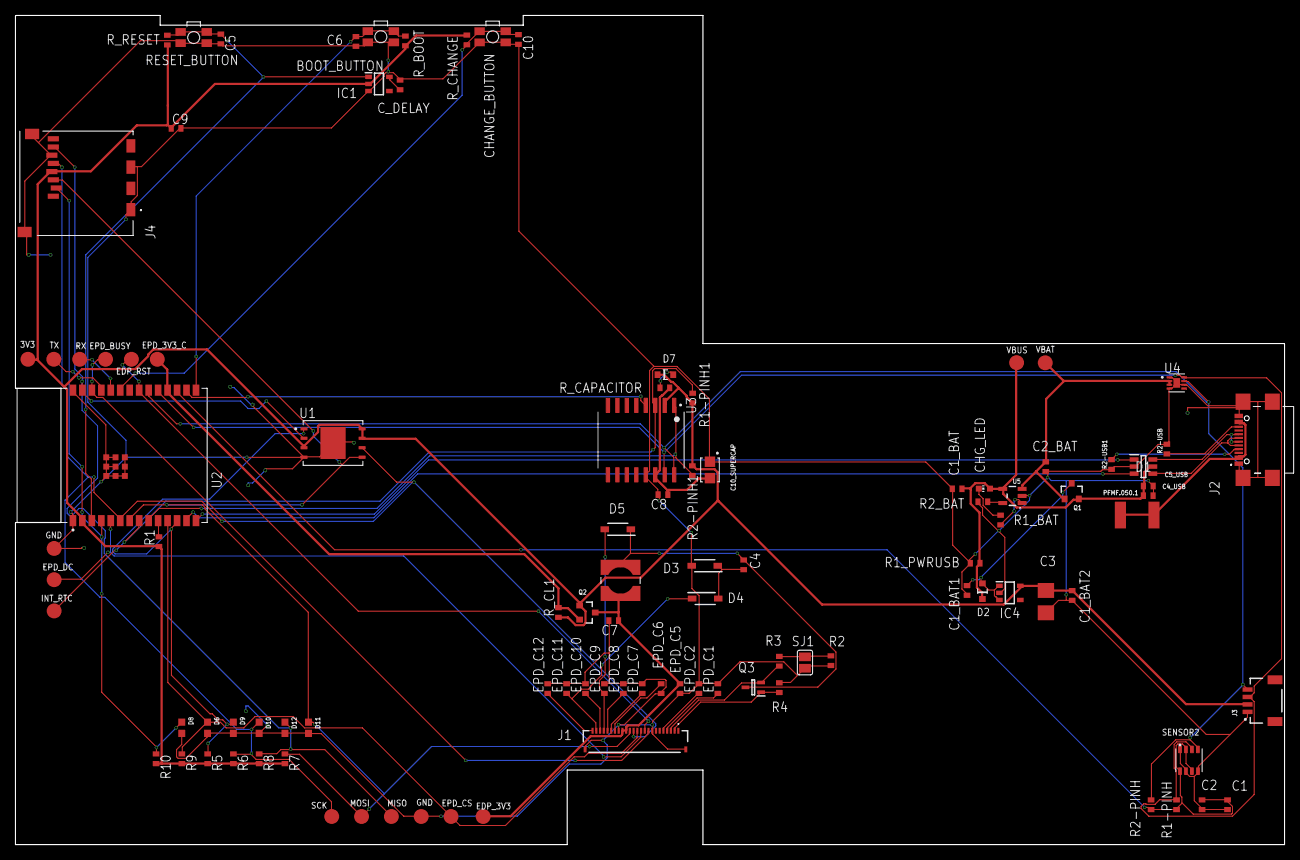
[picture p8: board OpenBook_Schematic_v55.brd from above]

Board: 2 copper layers, 170.2 x 111.2 mm, 103 parts (0 on the bottom side), 55 nets.

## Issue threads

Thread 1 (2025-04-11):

(SCHEMATIC) Avoidable warnings

filipdumitrascu, 2025-04-11:
-The pin overlap warning (from the erc check) can be avoided if you don't connect the qwiic/qt system directly to the gnd (pull the gnd to the left to be net between them).
-The frame1 has no value warning can be avoided if you assign a value (something insignificant).

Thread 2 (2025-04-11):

(PCB) 90 degree angle routing

filipdumitrascu, 2025-04-11:
Between sensor2 and J3, reset and boot button the routing is done with 90 degree angles.

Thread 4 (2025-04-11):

(3D) Button placement

filipdumitrascu, 2025-04-11:
Pcb buttons are not placed correctly according to the case.

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

Closed 2025-04-16.

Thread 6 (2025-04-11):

(PCB) Thickness

filipdumitrascu, 2025-04-11:
Board thickness should be 1mm, not 1.6 mm.
Go to Rules > Preferences > Design Preferences
Edit the description for good measure.
Go to the Layer Stack tab and check the "Edit material properties" option. Then double click on the 1.6mm and change the text to 1mm.

Closed 2025-04-16.

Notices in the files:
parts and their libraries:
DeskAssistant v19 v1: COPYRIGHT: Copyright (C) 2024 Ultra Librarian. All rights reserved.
